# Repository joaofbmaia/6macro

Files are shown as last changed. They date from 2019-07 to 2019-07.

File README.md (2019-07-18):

# 6macro
This is my first attempt at designing a keyboard. Is consists of a 6-key board intended for macros or as a dedicated controller for games with few bindings such as OSU.

RGB lighting is supported and the whole build is powered by an ATmega32U2 with the QMK firmware. The 6 switches are PCB-mounted.

The case is still a WIP and is built with stacked layers of laser-cut acrylic and a top layer of decorative aluminum.
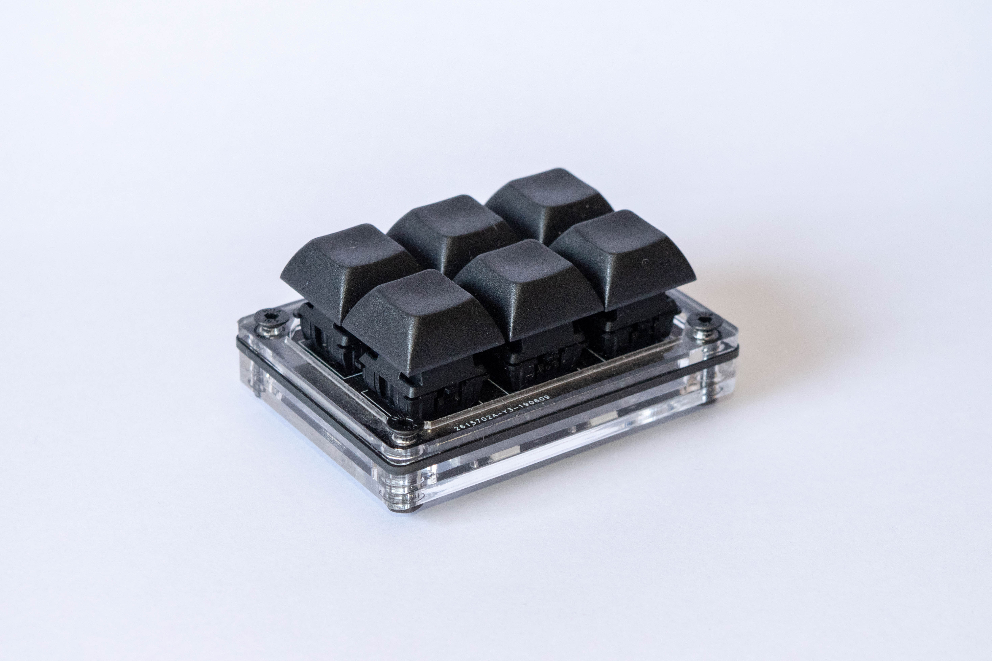
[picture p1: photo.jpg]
Photo of the keyboard

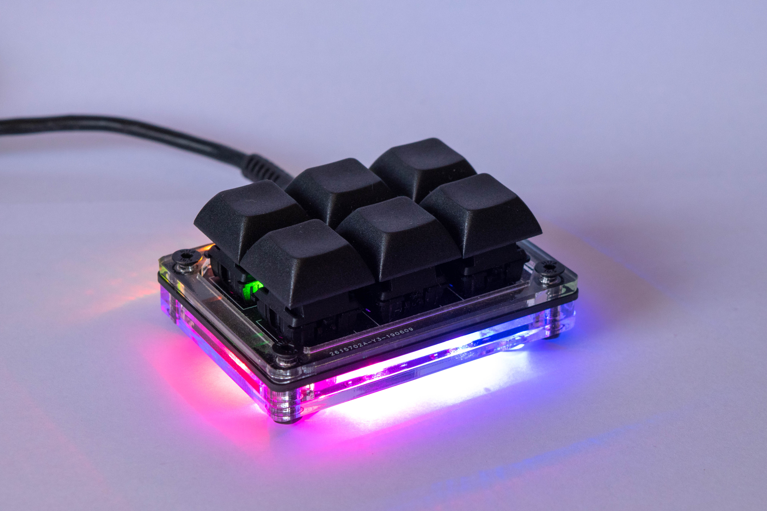
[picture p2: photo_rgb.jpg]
Photo of the keyboard with the RGB on

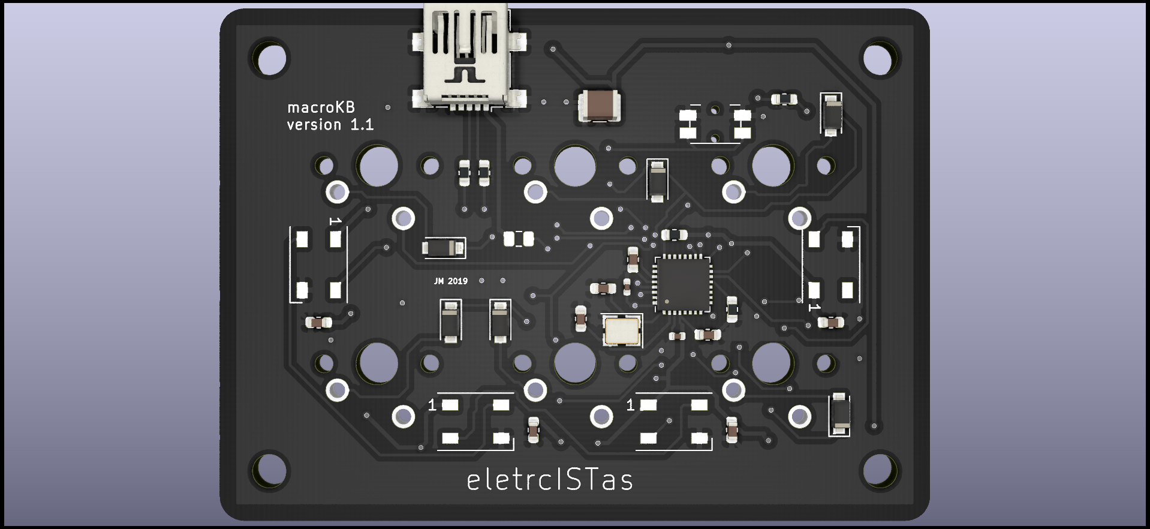
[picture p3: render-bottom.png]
Render of the PCB


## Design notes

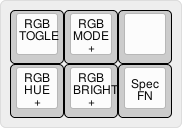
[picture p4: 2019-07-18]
layer1.png

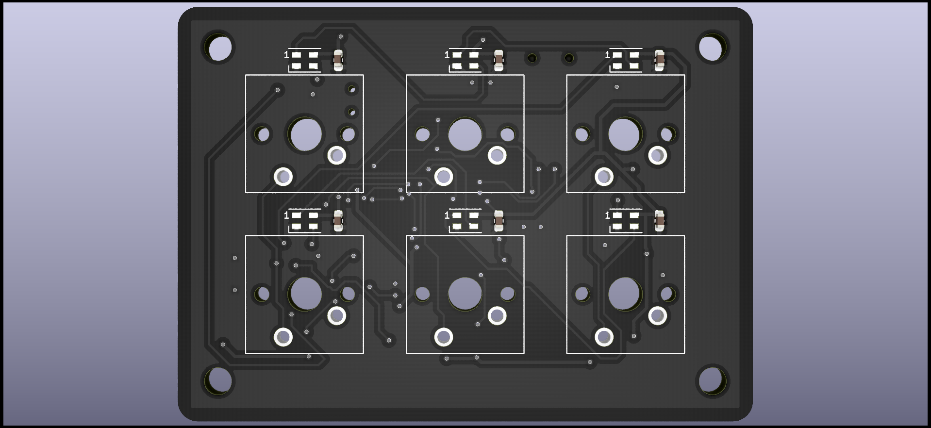
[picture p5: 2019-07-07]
render-top.png

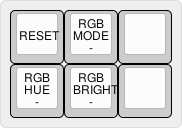
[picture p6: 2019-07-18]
layer2.png

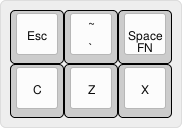
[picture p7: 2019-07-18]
layer0_osu.png

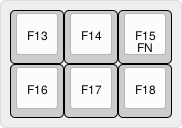
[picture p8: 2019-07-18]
layer0_default.png

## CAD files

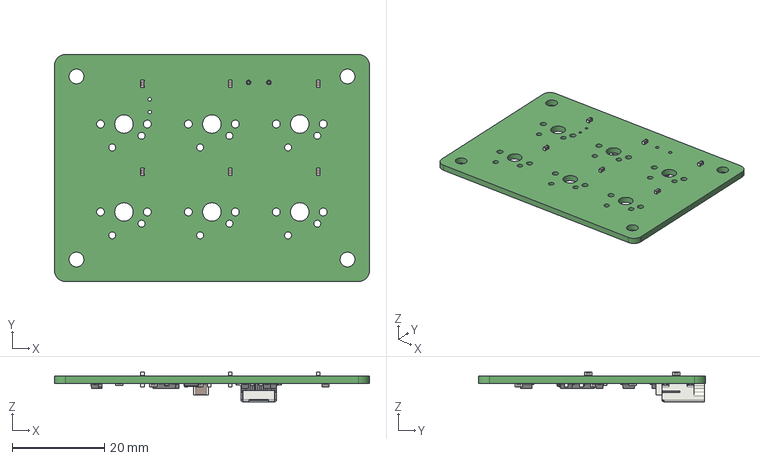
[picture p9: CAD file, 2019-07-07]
macro-kb.step
68.3 x 49.2 x 6.50 mm

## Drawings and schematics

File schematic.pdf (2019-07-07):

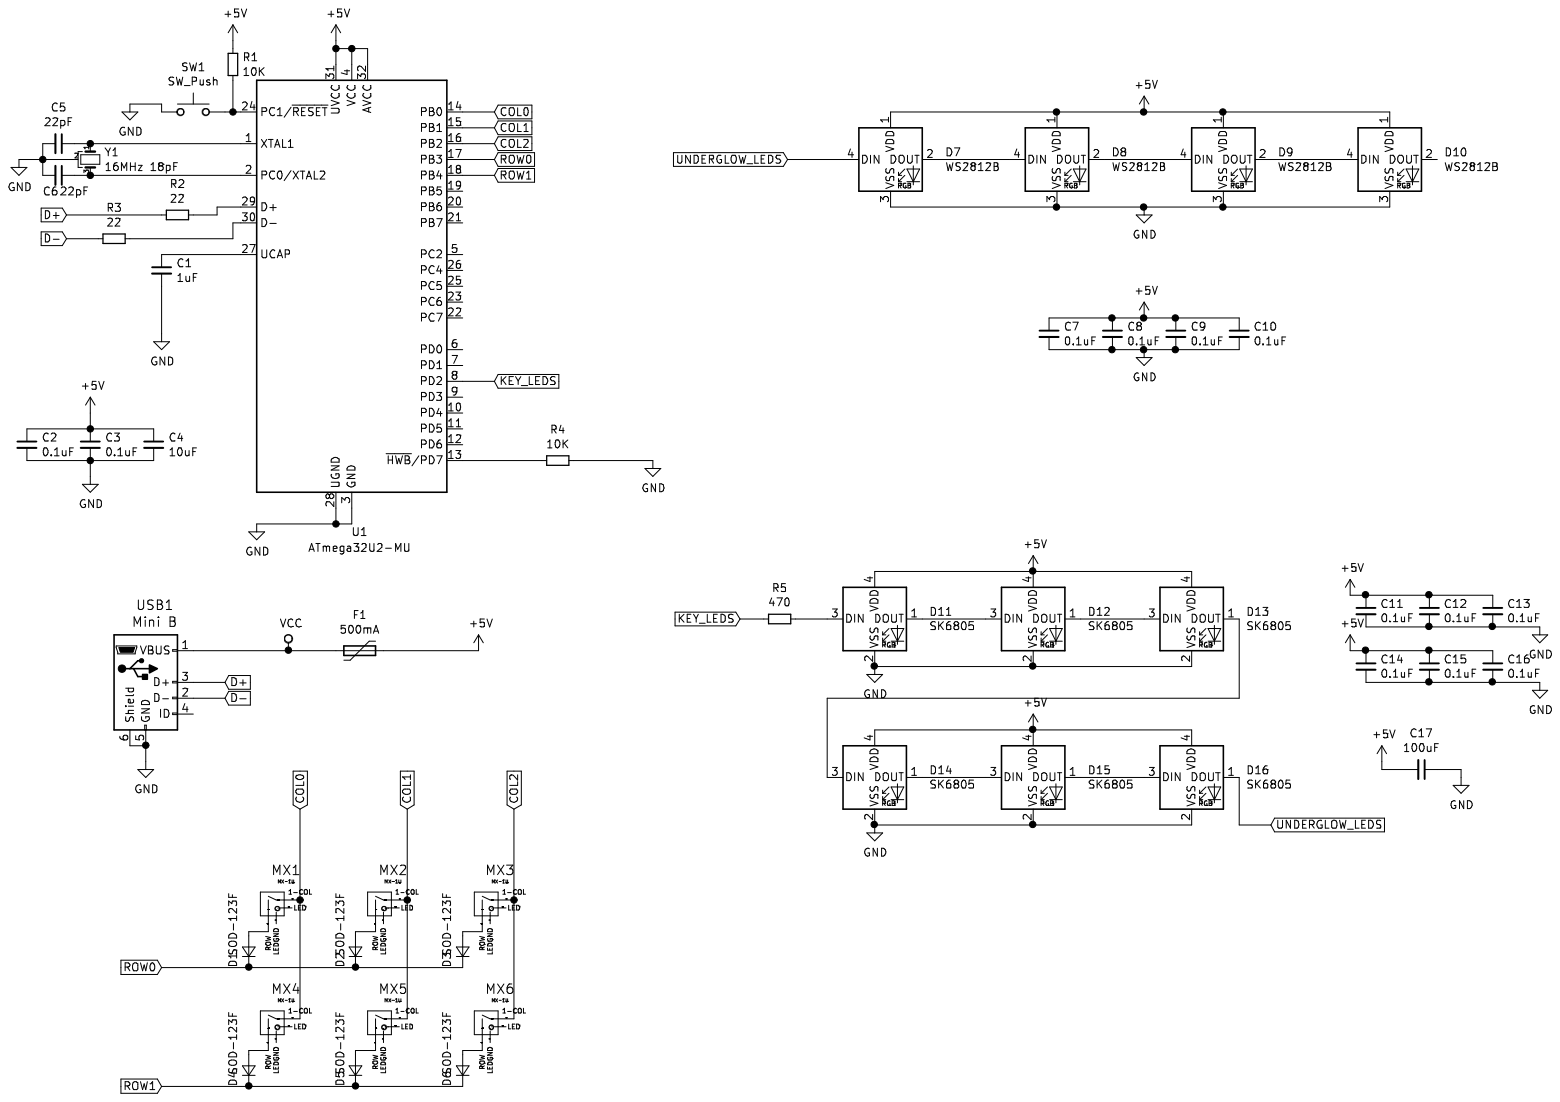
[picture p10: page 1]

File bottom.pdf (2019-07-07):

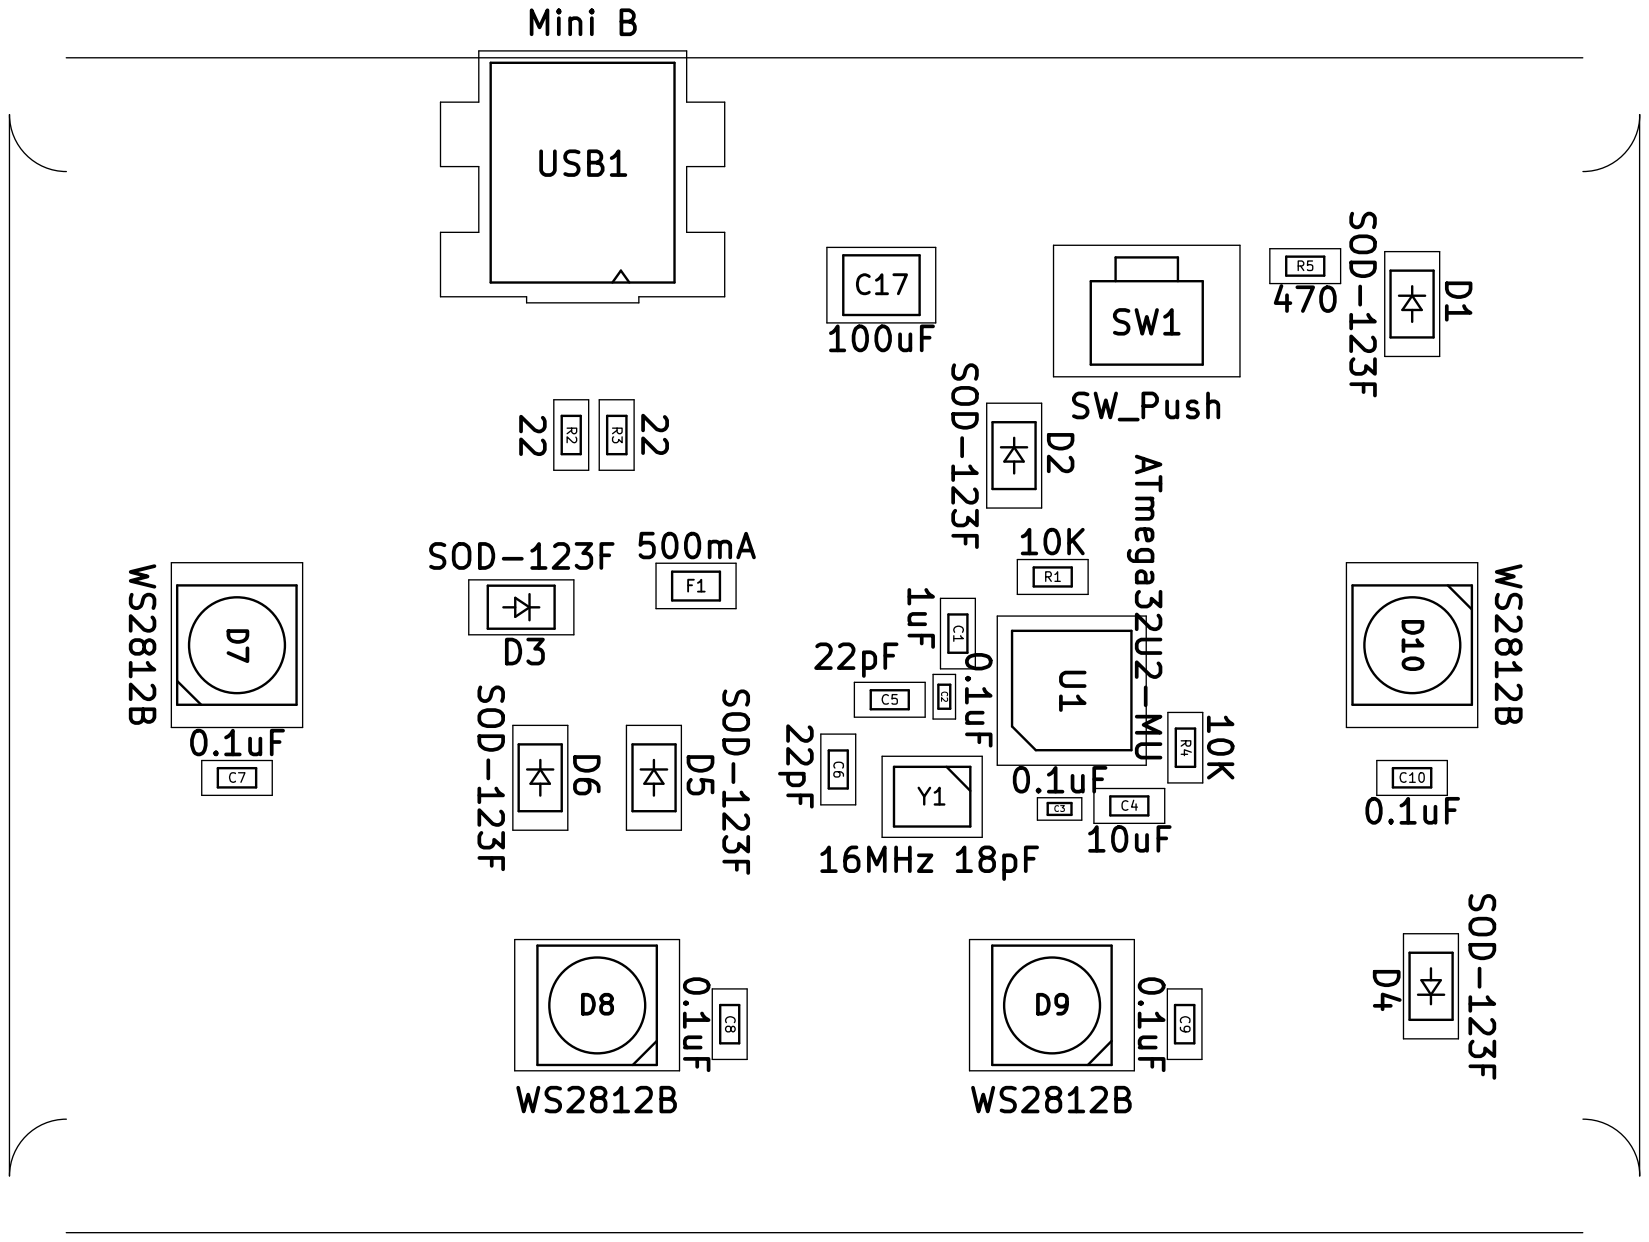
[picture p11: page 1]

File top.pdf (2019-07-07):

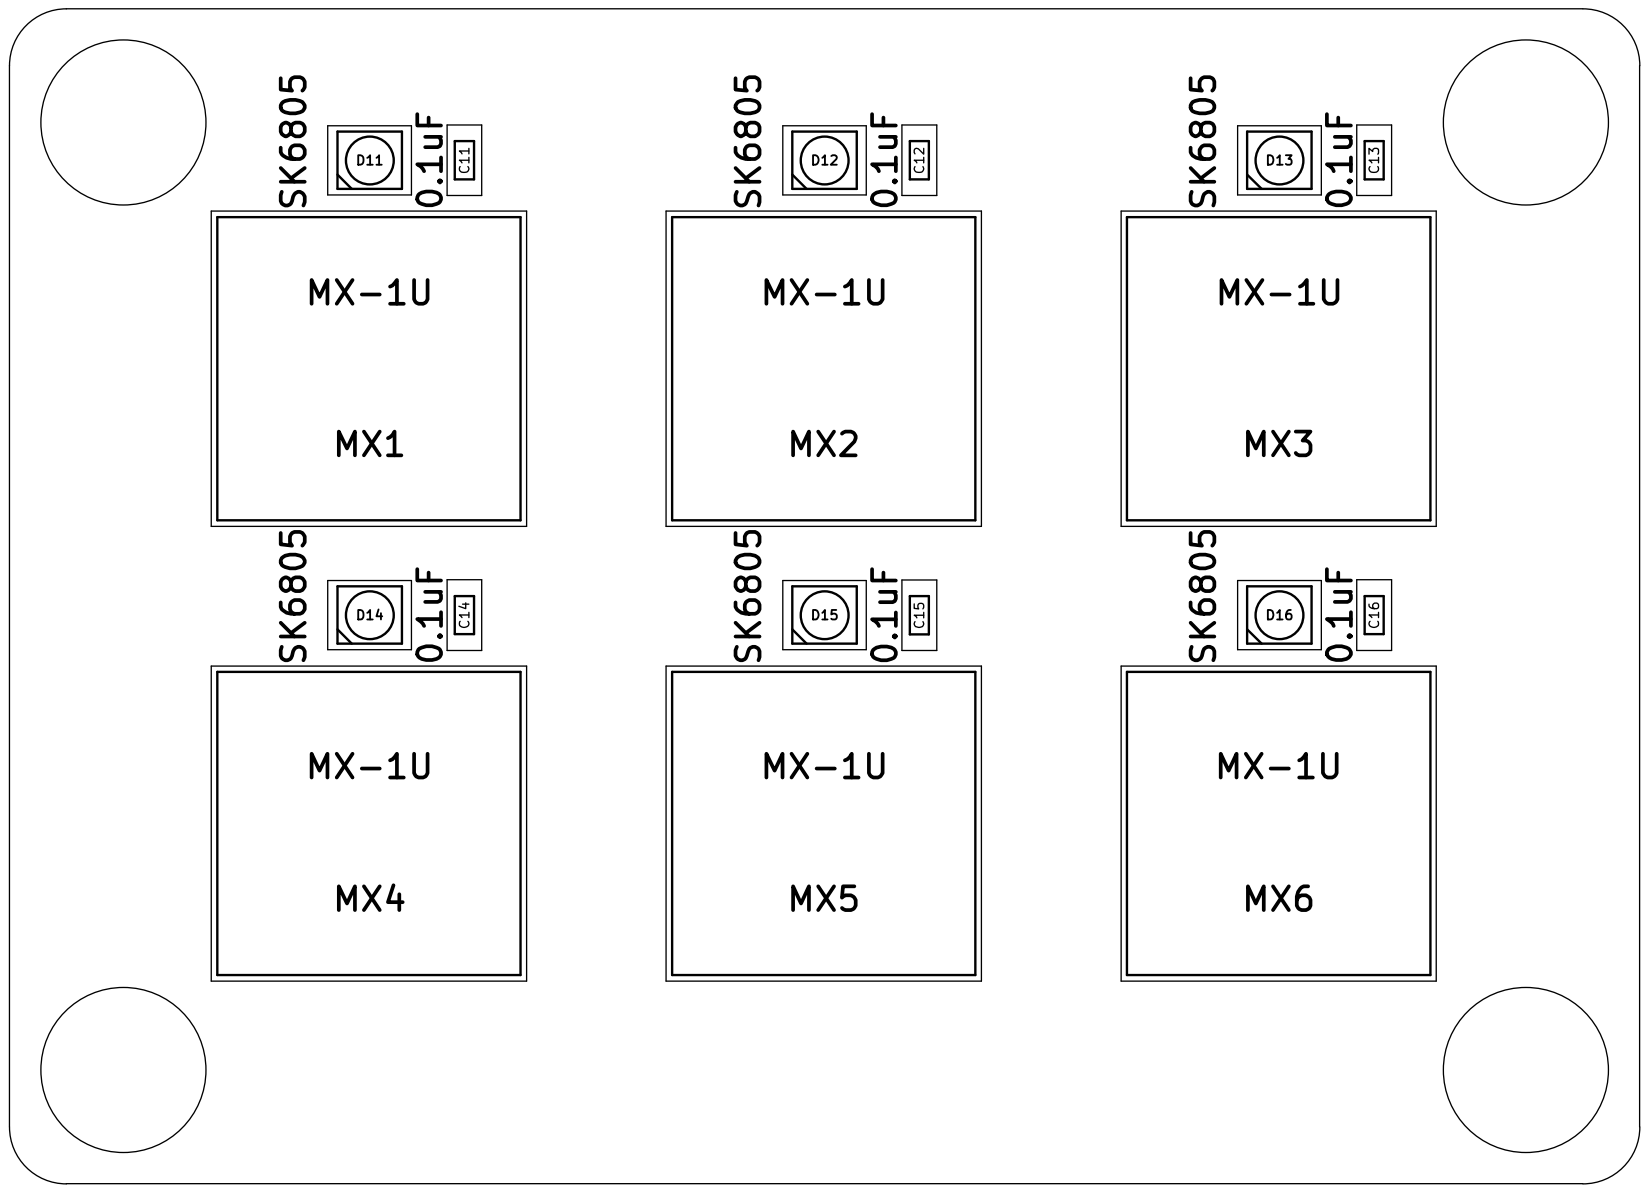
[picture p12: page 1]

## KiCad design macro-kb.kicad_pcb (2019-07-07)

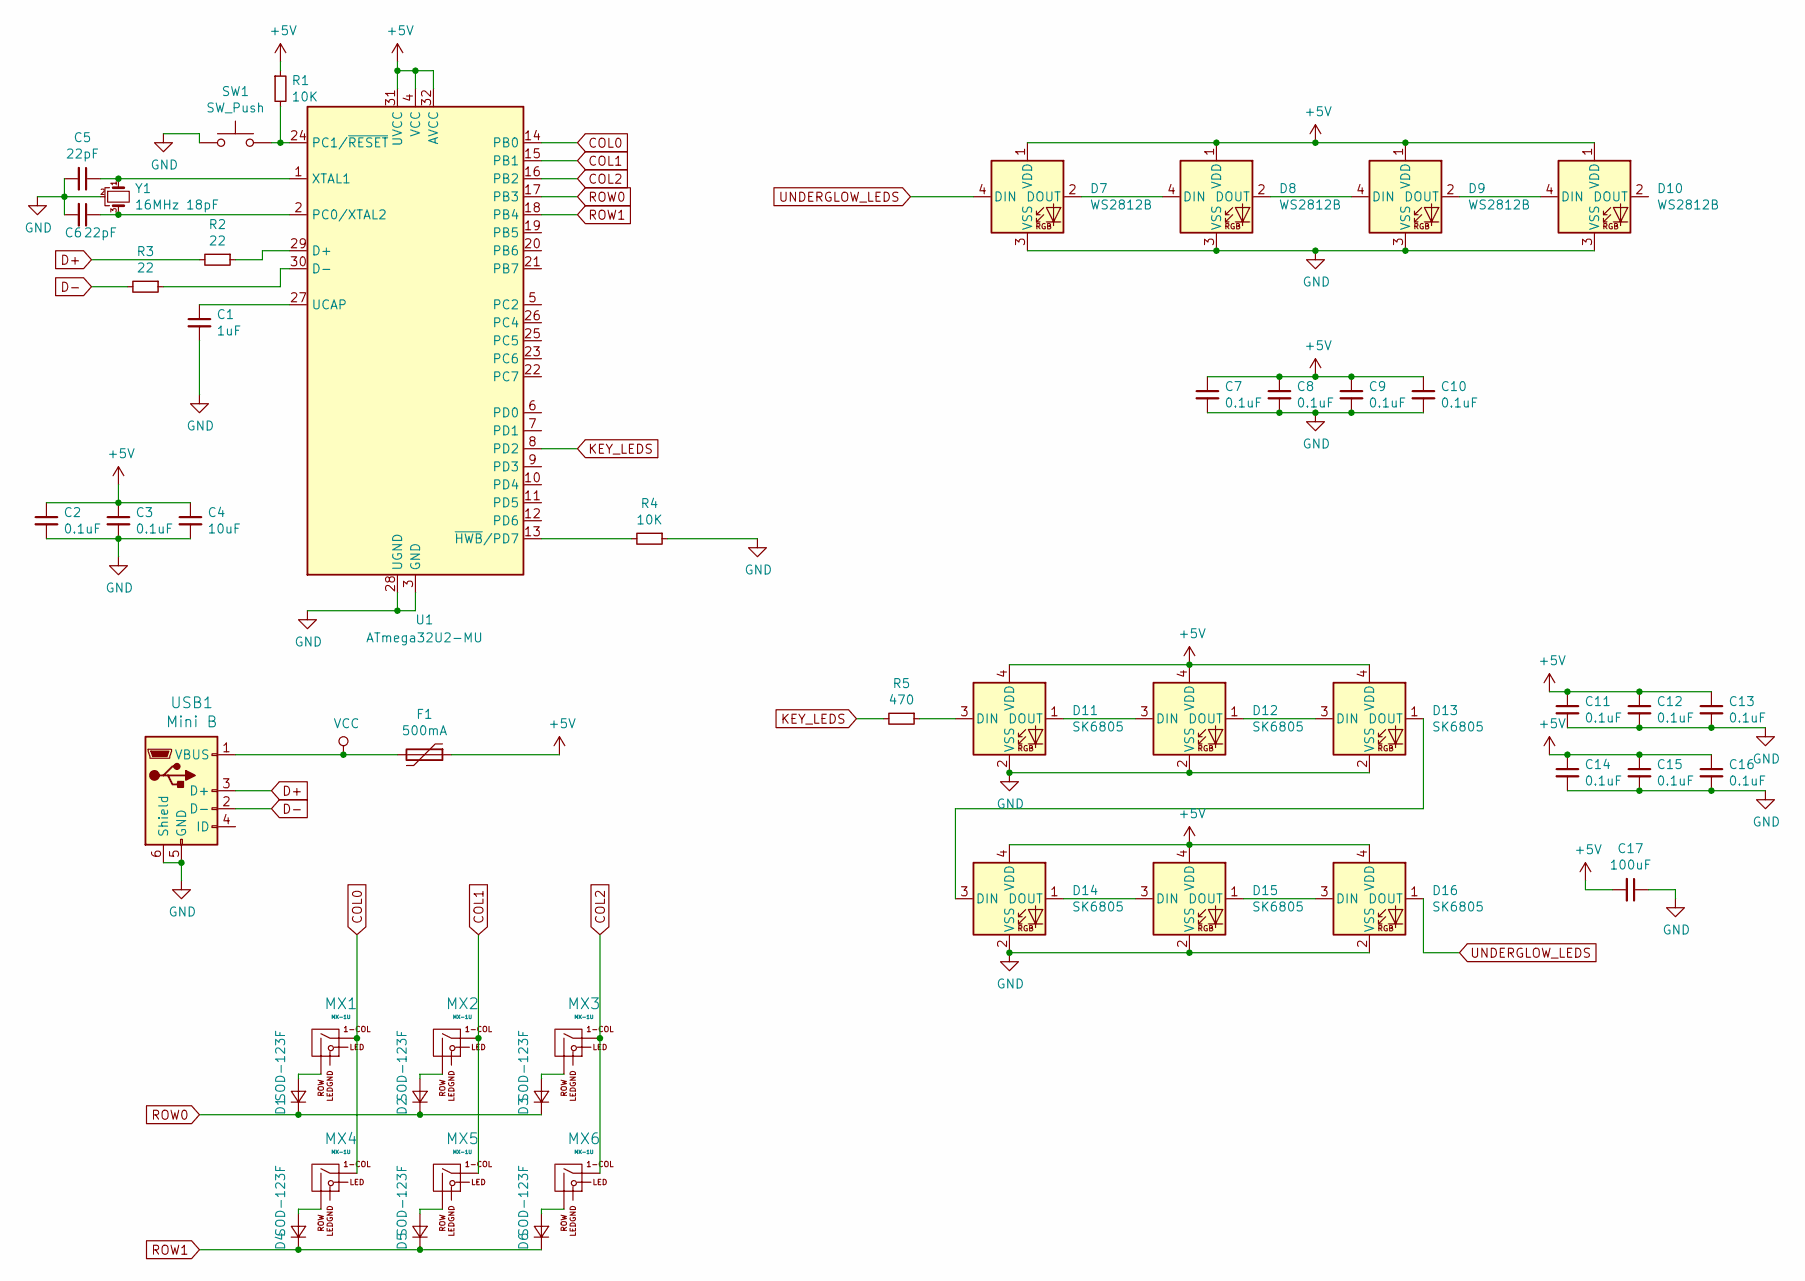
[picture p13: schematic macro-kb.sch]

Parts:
C1: 1uF; C_0603_1608Metric
C2, C3: 0.1uF; C_0402_1005Metric
C4: 10uF; C_0603_1608Metric
C5, C6: 22pF; C_0603_1608Metric
C7, C8, C9, C10, C11, C12, C13, C14, C15, C16: 0.1uF; C_0603_1608Metric
C17: 100uF; C_1210_3225Metric
D1, D2, D3, D4, D5, D6: SOD-123F; D_SOD-123F
D7, D8, D9, D10: WS2812B; LED_WS2812B_PLCC4_5.0x5.0mm_P3.2mm
D11, D12, D13, D14, D15, D16: SK6805; LED_SK6805_PLCC4_2.4x2.7mm_P1.3mm
F1: 500mA; Fuse_0805_2012Metric
MX1, MX2, MX3, MX4, MX5, MX6: MX-1U; SW_Cherry_MX_1.00u_PCB
R1, R4: 10K; R_0603_1608Metric
R2, R3: 22; R_0603_1608Metric
R5: 470; R_0603_1608Metric
SW1: SW_Push; Panasonic_EVQPUL_EVQPUC
U1: ATmega32U2-MU; QFN-32-1EP_5x5mm_P0.5mm_EP3.1x3.1mm
USB1: Mini B; USB_Mini-B_Lumberg_2486_01_Horizontal
Y1: 16MHz 18pF; Crystal_SMD_3225-4Pin_3.2x2.5mm

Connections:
+5V: C2.1, C3.1, C4.1, C7.1, C8.1, C9.1, C10.1, C11.1, C12.1, C13.1, C14.1, C15.1, C16.1, C17.2, D7.1 (VDD), D8.1 (VDD), D9.1 (VDD), D10.1 (VDD), D11.4 (VDD), D12.4 (VDD), D13.4 (VDD), D14.4 (VDD), D15.4 (VDD), D16.4 (VDD), F1.1, R1.1, U1.4 (VCC), U1.31 (UVCC), U1.32 (AVCC)
COL0: MX1.1 (COL), MX4.1 (COL), U1.14 (PB0)
COL1: MX2.1 (COL), MX5.1 (COL), U1.15 (PB1)
COL2: MX3.1 (COL), MX6.1 (COL), U1.16 (PB2)
D+: R2.2, USB1.3 (D+)
D-: R3.2, USB1.2 (D-)
GND: C1.2, C2.2, C3.2, C4.2, C5.2, C6.2, C7.2, C8.2, C9.2, C10.2, C11.2, C12.2, C13.2, C14.2, C15.2, C16.2, C17.1, D7.3 (VSS), D8.3 (VSS), D9.3 (VSS), D10.3 (VSS), D11.2 (VSS), D12.2 (VSS), D13.2 (VSS), D14.2 (VSS), D15.2 (VSS), D16.2 (VSS), R4.1, SW1.1, U1.3 (GND), U1.28 (UGND), U1.33 (GND), USB1.5 (GND), USB1.6 (Shield), Y1.2
KEY_LEDS: R5.2, U1.8 (PD2)
unnamed: C1.1, U1.27 (UCAP)
unnamed: C5.1, U1.1 (XTAL1), Y1.1
unnamed: C6.1, U1.2 (PC0/XTAL2), Y1.3
unnamed: D1.2 (A), MX1.2 (ROW)
unnamed: D2.2 (A), MX2.2 (ROW)
unnamed: D3.2 (A), MX3.2 (ROW)
unnamed: D4.2 (A), MX4.2 (ROW)
unnamed: D5.2 (A), MX5.2 (ROW)
unnamed: D6.2 (A), MX6.2 (ROW)
unnamed: D7.2 (DOUT), D8.4 (DIN)
unnamed: D8.2 (DOUT), D9.4 (DIN)
unnamed: D9.2 (DOUT), D10.4 (DIN)
unnamed: D11.1 (DOUT), D12.3 (DIN)
unnamed: D11.3 (DIN), R5.1
unnamed: D12.1 (DOUT), D13.3 (DIN)
unnamed: D13.1 (DOUT), D14.3 (DIN)
unnamed: D14.1 (DOUT), D15.3 (DIN)
unnamed: D15.1 (DOUT), D16.3 (DIN)
unnamed: R1.2, SW1.2, U1.24 (PC1/~RESET)
unnamed: R2.1, U1.29 (D+)
unnamed: R3.1, U1.30 (D-)
unnamed: R4.2, U1.13 (~HWB~/PD7)
ROW0: D1.1 (K), D2.1 (K), D3.1 (K), U1.17 (PB3)
ROW1: D4.1 (K), D5.1 (K), D6.1 (K), U1.18 (PB4)
UNDERGLOW_LEDS: D7.4 (DIN), D16.1 (DOUT)
VCC: F1.2, USB1.1 (VBUS)

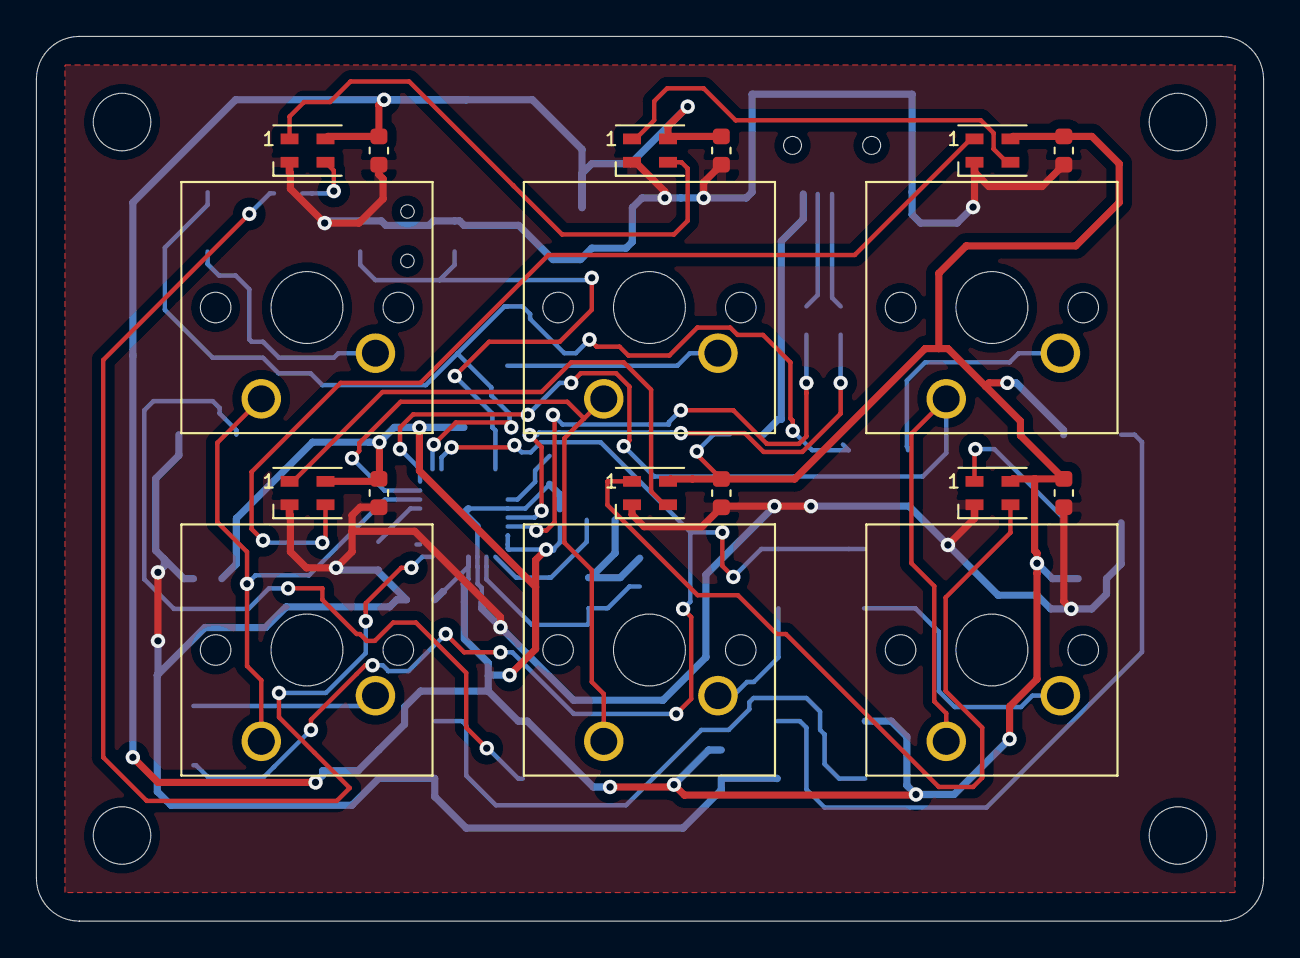
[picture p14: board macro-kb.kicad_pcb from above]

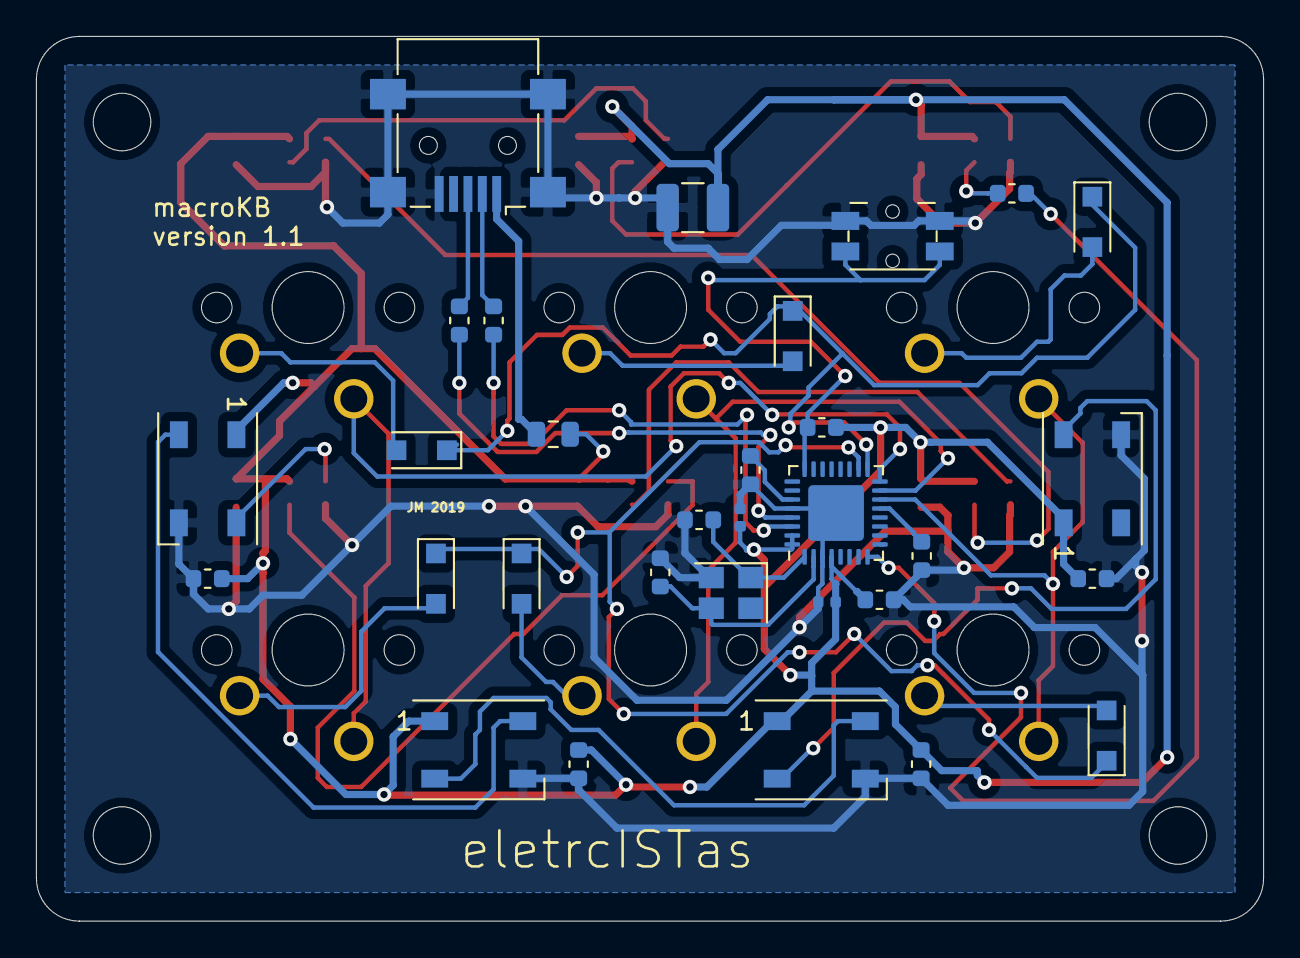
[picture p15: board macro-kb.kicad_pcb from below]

Board: 2 copper layers, 68.3 x 49.2 mm, 49 parts (31 on the bottom side), 34 nets.

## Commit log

2019-05-26 basic schematic
2019-06-08 final version (hopefully)
    [macro-kb-B_Cu.gbl, macro-kb-B_Mask.gbs, macro-kb-B_SilkS.gbo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]
2019-07-07 new renders
    [macro-kb.kicad_pcb]
2019-07-07 fixed crossed USB lines v1.1
    [macro-kb-B_Cu.gbl, macro-kb-B_Mask.gbs, macro-kb-B_SilkS.gbo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]
2019-07-07 new 3d model v1.1
    [macro-kb.step]
